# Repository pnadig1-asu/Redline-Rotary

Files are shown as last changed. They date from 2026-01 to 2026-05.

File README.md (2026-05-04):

<<<<<<< Updated upstream
This is the redline github repository

Phase 1 Video
https://youtu.be/27UCl4HXXh4

Phase 1 report can be found with the file name "MEE 342 Phase 1 Report.pdf" in the Github
=======

Phase 2 Video: https://www.youtube.com/watch?v=lnX_TSrsm9A

Phase 2 report can be found with the file name "MEE 342 Project Phase 2.pdf" in the Github
>>>>>>> Stashed changes

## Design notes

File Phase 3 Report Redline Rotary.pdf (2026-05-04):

Video: https://youtu.be/im36eBFv-yQ

### 1. Phase 3 report:

o Fabrication details (filament type, printer, settings, number of reprints) o Assembly procedure and challenges
o Test procedures, results, and interpretation
o Comparison with Phase 2 predictions (where applicable)
o Detailed discussion of failures, mistakes, and surprises
o Concrete list of design changes you would implement in a second iteration

### 2. Phase 3 video: Prototype Demo & Reflection

o Show the physical prototype operating.
o Demonstrate at least one test.
o Discuss major issues encountered and key lessons learned.

Phase 3 Report

Fabrication details
For this project, we used 2 bambu labs printers, mainly the bambu labs A1 mini and secondarily a P1S printer. The filament used was PLA plastic and with layer heights of .28 mm with supports enabled. The only part that needed to be reprinted was the rotors because the original print’s supports were not adequate enough, causing some overhang error. The print was also printed at 50% scale in order to preserve filament and print time.

Assembly procedure and challenges
For assembly, a lot of the parts had to be sanded down in order to fit accordingly, with the tolerances being pretty tight for a lot of the parts in order for the replica to work properly. Some challenges include the 3D printed gears being difficult working together and also not being able to use real lubrication for the plastic model. The surface roughness also caused some issues with the print and would cause poor sealing. The apex seals were not printed to stop the friction from being too overpowering to turn the rotors. Lastly, printing in PLA plastic means that the model would not be very heat resistant and not be able to support actual combustion.

Comparison with Phase 2
When comparing the phase two part of this project we can see that some predictions of tolerance issues were correct as there are some contact issues between the rotors and the housing. This is easily solved by sanding down the rotors slightly to make room for smooth rotation while still being true to our original model. Overall phase 3 was just printing our model from phase two, however in the printing process there were some techniques used to improve the models operation. For example printing parts in a certain orientation so the printing lines are in the direction of movement or rotation instead of against which would increase friction and make the model run rougher.

Details of failures, mistakes, and surprises
During the printing process the eccentric shaft was very hard to print compared to all of the other parts because of its complex geometry. It required many reprints and tree support additions to make it work, these tree supports increased the amount of rough surfaces that needed to be sanded down but wasn't too big of a deal. One mistake/failure would be a slight tolerance issue between the rotor and housing that made operation rougher and more difficult.

Test Procedure
Initial testing of the rotary engine was conducted by manually rotating the assembly to check for proper movement and clearance of all components. Observations focused on rotational resistance, consistency of motion and interference between specific parts. Following the initial evaluation, modifications were made to improve the prototype. The rotor and driveshaft were sanded to reduce roughness, and a lubricant was applied to decrease rotational resistance further. Additionally, the inner surface of the rotor housing was sanded as well to improve smoothness and better approximate the low friction conditions present in real rotary conditions. The model was then re-tested for rotational resistance under the same conditions

Results and Interpretation
During initial operation, the model exhibited significant rotational resistance and occasional binding due to the tight tolerances and relatively rough surface finishes of some of the higher tolerance parts, most notably the rotor, driveshaft, and rotor housing inner walls. After surface finishing and lubrication, the rotational motion improved significantly, requiring less effort to operate and resulting in more uniform motion of the rotor.

The observed improvements in rotational motion and elimination of binding is consistent with fundamental engine mechanics. In real rotary engines, journal bearings and continuous oil lubrication drastically reduce friction and wear between the rotor and shaft. Additionally, chromium plated housing inner walls provide highly efficient low friction surfaces for rotor motion. By smoothing the components using sandpaper and applying a graphite based lubricant, the model more closely replicates real rotary engine conditions and allows others to understand the mechanical properties of these engines. The results indicate that surface finish and lubrication are critical factors in achieving smooth and efficient rotary engine operation.

Design Changes in a Second Iteration:
Apex seals, ball bearings, better material(more heat resistant plastic)
For a second iteration, we would improve our prototype by moving beyond the current PLA used and focusing more on durability, sealing and smoother motion. Adding apex seals at the rotor tips to the prototype would greatly reduce the leakage between chambers. Integrating ball bearings to the design would help reduce friction, improve shaft alignment and make overall rotor movement smoother and consistent. We would make the second iteration out of a more heat resistant material such as a plastic or ABS. This would help better handle friction and temperature rise in operation of the prototype. These changes would make our design more mechanical, reliable and closer to a completely functional prototype of a wankel rotary engine.

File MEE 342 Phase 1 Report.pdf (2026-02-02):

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
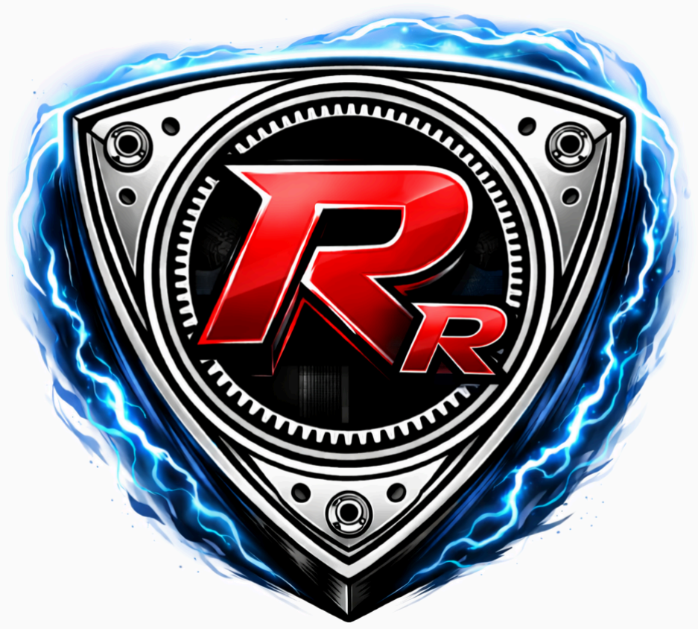
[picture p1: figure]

Phase 1

https://youtu.be/27UCl4HXXh4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 Executive Summary

The Wankel rotary engine converts the chemical energy of gasoline into mechanical torque using a rotating triangular rotor instead of reciprocating pistons. Unlike conventional internal combustion engines, it operates within an epitrochoid-shaped housing and produces power through continuous rotary motion, resulting in smoother operation, fewer moving parts, and a high power-to-weight ratio.
Each rotor creates three separate combustion chambers that simultaneously cycle through intake, compression, combustion, and exhaust phases. The rotor turns on an eccentric shaft with a fixed gear relationship, where the shaft rotates three times for every one rotor revolution. Proper operation depends on tightly sealed chambers, controlled air-fuel mixture, spark ignition, and effective lubrication and cooling systems. Many designs also inject oil into the intake flow to lubricate seals.
Key subsystems include the fuel delivery system, lubrication network, spark ignition system, and either air or liquid cooling. The most critical components for durability are the apex and side seals, their spring loading, and the thermal and lubrication controls that protect them.

Primary failure modes include apex seal wear or fracture, bearing damage from poor lubrication or overspeed, overheating and thermal distortion, and oil metering failures. Seal failure is especially critical because it leads to compression loss and major performance degradation.

The reference design described is a scaled version of a 1.3 L rotary engine with a 2:3 stationary-to-rotor gear ratio, defined rotor geometry, and tight sealing tolerances. Rotary engines are commonly used where compact size, smooth operation, and high power density are valuable, including UAV systems, automotive applications, and hybrid generator range extenders.

How the Wankel Rotary Engine works
Much like a conventional piston internal combustion engine, the purpose of the wankel rotary engine is to convert chemical energy from gasoline into mechanical energy. Also similarly, the engine does this by compressing and igniting air-fuel mixtures to harness the explosion’s energy as torque. Where the wankel rotary engine differs from traditional ICE’s is in its geometry; resulting in a unique set of advantages and disadvantages.
This engine is a reciprocating, four-stroke system that operates three combustion chambers per rotor assembly. That means that each unit of this engine intakes air-fuel mixture, compresses it, ignites it to harness energy, then forces out exhaust gases cyclically in three different instances concurrently. It accomplishes this using an epitrochoid-shaped housing with a curvilinear equilateral triangle shaped rotor inside that rotates on a 3:1 speed ratioed eccentric crankshaft. This system is then completed by sealing the combustion chamber, adding intake and exhaust ports, then typically a spark-plug ignition system and appropriate cooling and lubrication systems.

Key Components

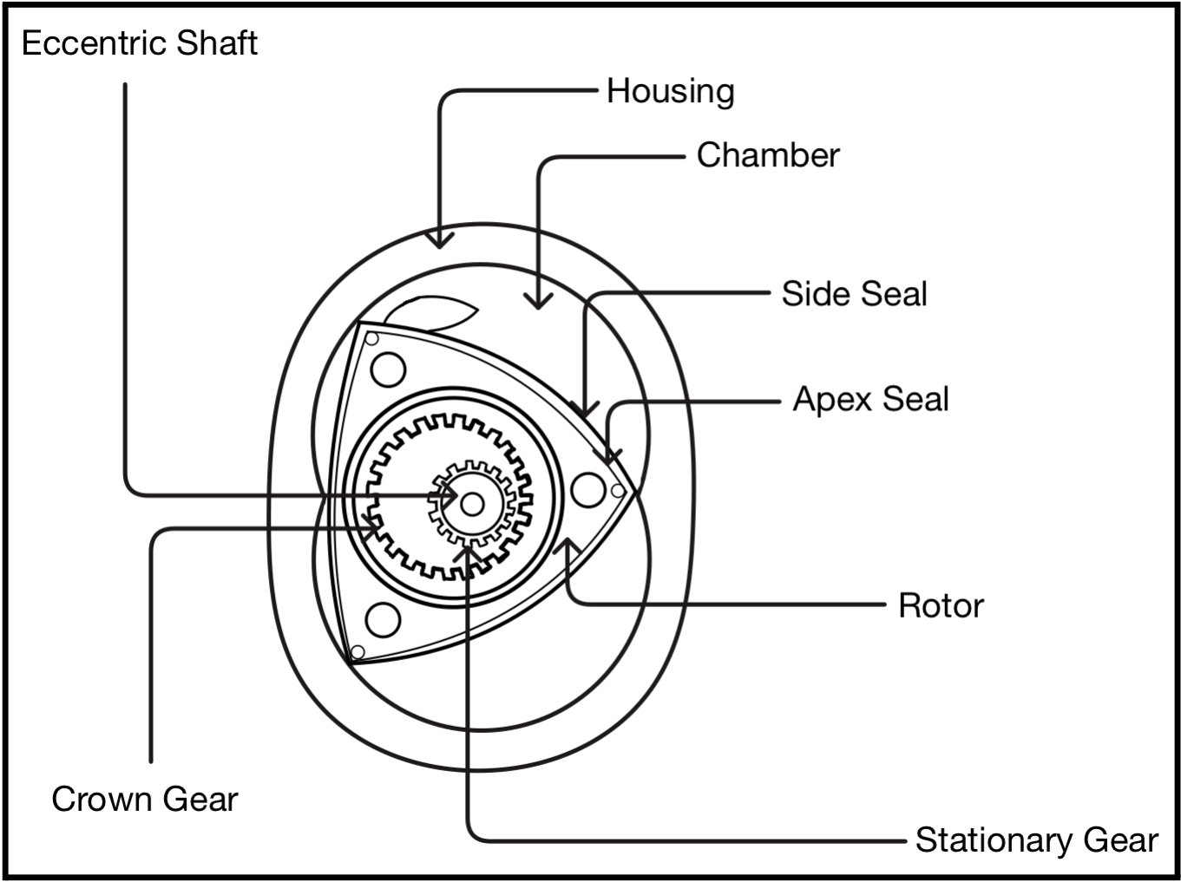
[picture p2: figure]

Housing (aluminum with chrome plating) Rotor (cast iron)
Eccentric shaft (machined steel) Stationary gear (hardened cast iron) Rotor bearing (aluminum)
Spark plug (iridium aluminum oxide) Apex seal (and springs) (graphite) Side seal (and springs) (steel) Coolant/Oil O-rings (viton)

Subsystems
Fuel system - This engine requires a precise air-fuel mixture to achieve proper combustion. Fuel is mixed with air through a carburetor or fuel-injection system. A crankshaft angle sensor, exhaust gas oxygen content (lambda) sensor, and air pressure sensor may be used to optimize fuel quantity and mixture timing. Many wankel systems mix lubrication into air-fuel mixture much like a two-stroke engine.
Lubrication system - The rotor bearing is the main point of lubrication in a wankel rotary engine. The bearing is oiled by passages through the middle of the crankshaft that contain pressurized oil from the oil pump. Oil then circulates around the rotor bearing and through the inside of the rotor. Oil can also be mixed into the air-fuel mixture to lubricate external rotor seals like the apex and side seals.
Spark system - Very few compression ignition wankel rotary engines exist, meaning spark ignition is common practice due to consistency and engine knock prevention. Either crank angle sensor or magneto spark systems are implemented to ignite non-CI fuels.
Cooling system - Depending on application, water cooling may be needed to keep engine temperatures within operating range. Smaller UAV applications utilize fins for air cooling, while automotive applications use coolant passages, a water pump, and a radiator. An oil cooler is sometimes utilized to include cooling from the lubrication core of the system.

Failure Modes
Seal destruction:
- Detonation (usually due to overheating)
- Lubrication problems
Bearing destruction:
- Lubrication problems
- Revving too high
Overheating/thermal distortion:
- Poor cooling design
- Uneven heat rejection
Oil Metering Failure:
- Pump/injector malfunction

The main failure mode is the apex seals, which provides sealing between each chamber on the tips of each triangular rotor. This can be caused by wear, improper lubrication between the components, or excess heat, which eventually leads to compression loss and power drop. Another cause of apex seal failure is detonation, which is when the air-fuel mixture combusts prematurely; the pressure from the detonation can shatter the apex seal while it is not in position to take that kind of force. This failure is catastrophic to engine operation, with reassembly only possible if loose seal pieces do not gash housing and rotor components.

The most important components to minimize failure are the material used for the apex seals, the apex seal springs, and the fuel, lubrication, and cooling systems. The apex seal material used changes the wear resistance and longevity of the seals. The seal springs are important because they make sure that the seals maintain consistent contact with the rotor, optimizing compression. All of the fuel, lubrication, and cooling systems are important components because if they are not operating properly, it could cause premature wear/overheating to the engine which would cause it to fail.

Critical design Parameters
Our design will be a scaled-down version of Mazda’s 13b wankel rotary engine.

The gear ratio of stationary gear to rotor gear is 2:3 with a teeth count of 36:54 some other critical dimensions being a radius of 105 mm from rotor center to apex seal point, chamber/rotor width of 80 mm.
Eccentric shaft diameter (rotor bearing diameter -> clearance)
Engine displacement 1.3L
15mm crank offset (stroke)
Sealing apex and side seals (too large of seals -> interference damage, too small -> no compression)
Epitrochoidal housing and curvilinear equilateral triangle rotors with widths of 80mm Crankshaft spins 3x as fast as the rotor, so one rotations of the rotor is 3 rotations of the crank

Applications
UAV - Single rotor, air cooled, small, high power to weight ratio, low vibration, fuel versatility Automotive - 2 or 3 rotor, coolant and oil cooled, larger displacements
Hybrid Power Generation - engine can act as a generator for electric motors with high fuel efficiency, can be used as a range extender

Kinematics
The kinematic relationship between the rotor and the stationary gear can be described as

ω

r = ω
c

(1 −

Ns
Nr

)

Where:
ω is the angular velocity of the rotor
r
ω is the angular velocity of the eccentric shaft
c
N is the number of teeth on the stationary gear
s
N is the number of teeth on the rotor gear
r

In most wankle applications,

Ns
Nr

=

2
3

Sources
https://patents.google.com/patent/US5305721A/en

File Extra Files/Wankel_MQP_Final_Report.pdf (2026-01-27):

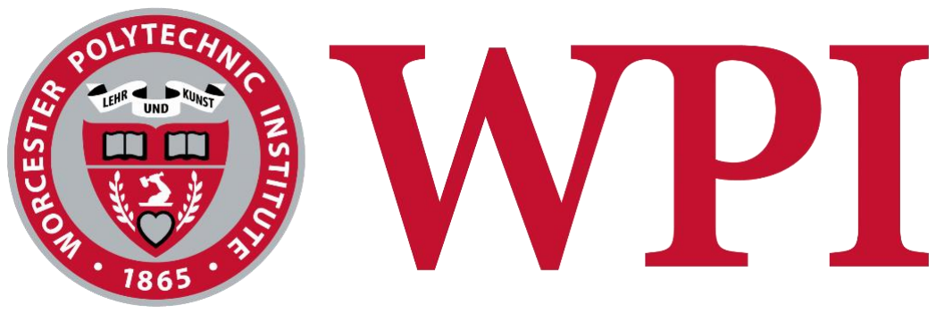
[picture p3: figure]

### Designing and Manufacturing a Rotary Wankel Engine

A Major Qualifying Project Submitted to the Faculty of WORCESTER POLYTECHNIC INSTITUTE
in partial fulfillment of the requirements for the Degree of Bachelor of Science in Mechanical Engineering

By:

William Hopkins
Patrick Leach
Yutai Han
Ryan Gillett

Advised By:

Selçuk I. Güçeri

24th of March 2023

This report represents the work of one or more WPI undergraduate students submitted to the faculty as evidence of completion of a degree requirement. WPI routinely publishes these reports on its website without editorial or peer review. For more information about the projects program at WPI, see http://www.wpi.edu/Academics/Projects. (https://www.wpi.edu/project-based-learning)

Abstract

Through thorough design and manufacturing, our team was able to model and construct a rotary engine. We did this by 1) researching different Wankel engines 2) computing the math for the engine shape 3) designing our model 4) machining the parts and 5) constructing the engine and testing it. Once these steps were completed, we had a functioning model of a Rotary Wankel Engine.

The Wankel engine is a type of rotary combustion engine that converts thermal energy into mechanical energy through eccentric rotation movement. Compared to the traditional Otto cycle combustion engine with reciprocal pistons, Wankel engines have fewer moving parts, and therefore are proven to be more compart and smooth during operation. As the world is moving into a unified effort of decarbonization and downsize of combustion engines, Wankel engines are slowly being brought back as a compact solution for source of energy. To have a better understanding of the operation of Wankel engines, and to produce a functioning prototype, the team conducted extensive literature examination and review of the early documents of the development of rotary engine.

Through extensive computation, the team was able to create the epitrochoid shape of the housing that the rotor is sitting in and create the rotor that has similar shape to a Rouleaux’s triangle with correlating dimensions. The material of the parts was selected accordingly from the team’s research on past development and within the parameter of the project budget allowance. The dimensions were then transferred to computer-aided design and manufacturing software to start the manufacturing process.

Executive Summary
Goals and Objectives

The goal of our team’s Major Qualifying Project was to design and manufacture a rotary Wankel engine; recreating the famous engine with modifications of our own to improve the system. In this MQP we worked with the manufacturing laboratory of Washburn at Worcester Polytechnic Institute to machine and construct our rotary Wankel engine.

Proposed Solutions

To carry out the manufacturing, we followed the designing and iterating process shown in many WPI classrooms. We defined our problem by reading articles and interviewing professor Güçeri on the downsides of the rotary engine. We mapped the process and determined the key metrics of the engine to focus on would be:
- Apex seal spring retention
- Electronically controlled ignition timing
- Material choice to avoid pitting and wear
Results

From our research, design, and manufacturing we created a Wankel engine with SolidWorks, Esprit, and the machining tools located in Washburn labs. SolidWorks allowed us to design each part to the specifications of Mazda and other Wankel examples and place it into an assembly for easy view of construction. The software Esprit was the transition from SolidWorks into CAM “g-code” which then allowed us to take our raw material and machine into the parts we needed.

Our newly constructed engine may not solve the downsides of previous Wankel engines, however with the rise of rotary engines once again, we were able to develop a deeper understanding of how the engine itself works. Our mission with this project includes a deeper understanding of a Wankel engine as well as insight and practice with advanced design techniques and manufacturing technologies through the manufacturing of an engine. Knowledge gained will be used demonstrate and explain to others how the engine itself functions.

Acknowledgements

### We would like to thank several individuals for their

contributions and support of this project.

Selçuk I. Güçeri, WPI Mechanical Engineering Professor, and our project sponsor, for supporting us throughout our MQP, guiding us on where we needed to go next, and his continuous support and enthusiasm for our project.

The Mazda Engineering Team for their base design of the Wankel Rotary engine, and their parameters for which we based ours of off. Without their data we would not have been able to accurately design the rotor or rotor housing without measuring a physical model. Their equations also allowed for the scalability of the parts.

The Mechanical Engineering Department for the use of Washburn Laboratories and for them ordering tooling and material for us to create our engine.

The L. S. Starrett Company for assistance with tooling and allowing us to cut our large stock pieces to size.

# Table of Contents

# Table of Figures

Introduction

Automobiles and similar modes of transportation are necessary for modern day lifestyles. These automobiles require engines, engines which already exist but may have glaring flaws. The goal of our team’s Major Qualifying Project was to design and manufacture a rotary Wankel engine; recreating the famous engine with modifications of our own to improve the system.

The combustion engine was the driving force behind the industrial revolution and the main powerhouse of human innovation for past decades. Many types of combustion engine were invented throughout the history intended to be used for different purposes. The most famous being the reciprocating piston engine that are commonly used in most of the motorized transportation. Other combustion engines include turbine engines mostly used in the aviation field, and the rotary engine; an alternative solution to the piston engine that has been utilized in different application.

The rotary engine’s initial application was in motorcycles, due to its relatively small size and high-power output. Rotary engine reached its peak popularity at the end of the 20th century, where Mazda motor corporation introduced it in a variety of the mass-produced road cars, as well as some high-performance race cars. However, the production of the rotary engine was slowly phased out at the turn the of century due to its relatively high consumption of fuel, and the inability to burn fuel cleanly. These were some of the deciding factors at the time; the scarcity of oil, and a general direction for automotive manufacturers to produce more efficient and clean burning cars. Even though the mass production of rotary engine equipped cars ended more than a decade ago, the search for a new application of rotary engine never stopped. Its unique design and compactness keep the search ever moving. There have been series of attempts to revive the rotary engine with modifications to the original design, or as a secondary source of power.. This project will focus on having a rotary engine which is smaller in size than the regular Mazda motor, performing on a similar power to weight ratio.

Background

The rotary Wankel engine was first designed by German engineer Felix Wankel in 1929. The engine was designed to create rotational motion by converting pressure, providing more unform torque, less vibrational movement, and to have a lighter weight than the average piston engine (Hege, 2015). NSU Motorenwerke AG acquired the patent, then licensed the design to other companies around the world.

The rotary engine has a four stroke cycle similar to a piston engine. However, the combustion cycles occur at different locations within the combustion chamber in the rotor housing. The intake, compression, and exhaust of the air is all controlled by the rotation of the rotor, while the spark plug located on the housing ignites the compressed air to initiate the ignition stage. Due to the decreased number of the moving parts in the combustion chamber, rotary engines are able to achieve a higher revolution per minute than traditional piston motors. A visual representation of a combustion cycle is shown below.

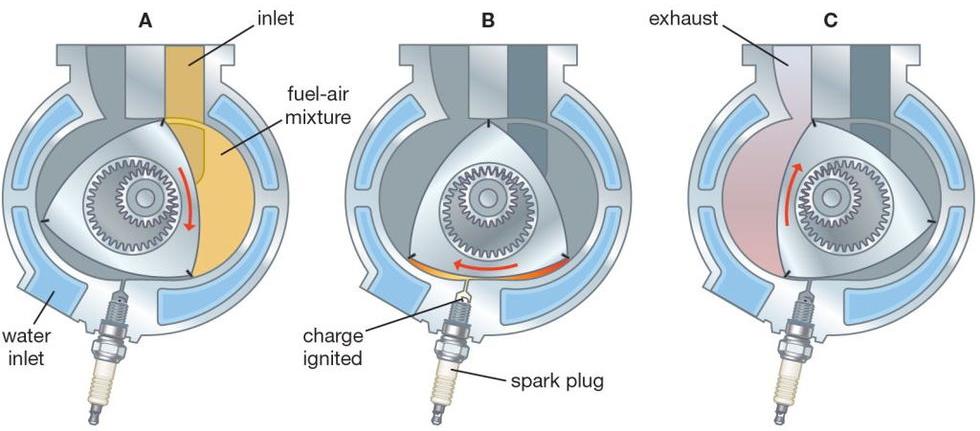
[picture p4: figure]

Figure 1: How a Wankel rotary engine works (Jancer, 2018)

Many of the major automotive companies such as Alfa Romeo, American Motors, Citroën, Ford, General Motors, Mazda, Mercedes-Benz, Nissan, Porsche, Rolls-Royce, Suzuki, and Toyota, purchased the license, attracted to its smoothness and light weightiness. Rotaries were utilized in airplanes, motorcycles, but mostly automobiles. Only a few of these companies ultimately followed through with the license however, Mazda, Citroën, and NSU continued to work on the engine. Mazda was the most influential and successful in their research and development on the Wankel engine. Over the years, Mazda has produced many famous cars with the Wankel such as the RX-7 FB, FC, and FD, the RX-8, the 787-B four rotor, and the Cosmo.

The Mazda RX-7 is one of the main sources of inspiration for this project. It is a wonderful automobile, one that has faded out of mainstream due to the issues which arise from the rotary Wankel engine. To revive the Wankel engine would be a magnificent feat, hence why our team has decided to redesign, improve, and construct the engine.

To design and build a rotary engine, there are many more requirements than one may expect. Researching the epitrochoid equations for the rotor housing and rotor requires intense analysis of Mazda technical books, online forums, and insight from Professor Güçeri. Then one must design and create the eccentric shaft, an offset shaft to convert the rotor motion into the drive train. This will require more research and a difficult manufacturing process. Once all the major components of the engine have been created, the seals, fasteners, and extra elements must be either purchased or handmade to construct a functional engine.

Methodology Timeline and Overview

A Term:
During the first of three terms in our group's development time, we began ideating, researching, and designing the engine, while also writing our final report. The three main components which were designed in CAD were the rotor, the rotor housing, and the eccentric shaft. All equations and shapes are modeled after Mazda’s patent for the rotary Wankel engine, specifically the 13B.

This process started with the equations for the rotor housing. First modeled in Desmos then SolidWorks, the equation below is foundation for the entire housing.

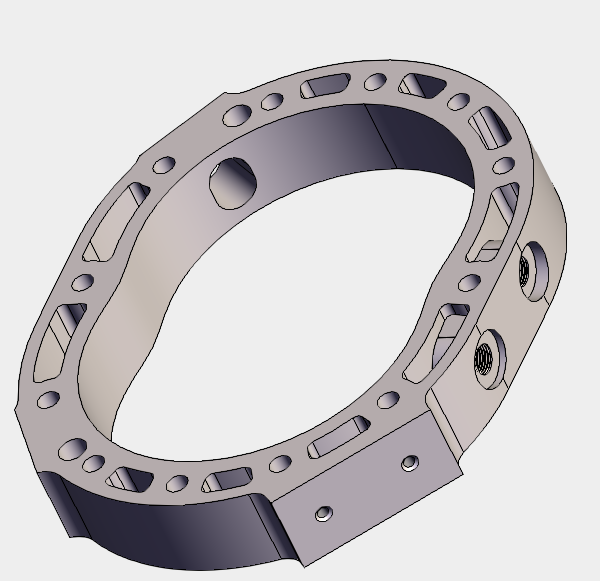
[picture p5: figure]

Figure 2: Rotor Housing

The rotor housing also needs many holes and supports to properly function in its design. Water cooling holes are strategically placed to allow more even cooling of the system. One of the downsides of the rotary engine compared to a piston engine is the uneven heating of the system. Exhaust and combustion take place in certain spots of the rotary, with one segment being just compression and intake, significantly cooler operations. Along with the cooling channels, intake, exhaust, spark plugs, and mounts all needed to be considered and included as well.

The next part of the assembly which was modeled was the rotor which goes within the rotor housing. The rotor is one of, if not the most, essential components of a rotary Wankel engine. To form the outline of the shape, Mazda does provide equations, however these equations are almost impossible to implement into SolidWorks. The equations are all cyclical, continuously calculating the distance from the rotor housing as it goes around in its epitrochoid shape.

The rotor has more components which improve its ability to function. First, there needs to be chambers on the edges for compression. These were determined by measuring the ones on Mazda’s rotor, and then scaling it down. In the center of the rotor there is gear teething which connects the rotor to the eccentric shaft. In the final stages of construction, there will be seals along the edge of the gear hole.

The third component which our team began to design and develop was the eccentric shaft. This is one of the more necessary parts for the engine to run. The eccentric shaft is what takes the rotational motion of the rotor and transfers it to the drivetrain. In the simplest terms, it is the connector from the engine to the transmission to then turn the wheels. In theory, the eccentric shaft is a simple piece, a cylinder with some eccentricity set at 3.5/6.2 or 0.5645in. There are not many extra holes, or components coming from it. The issue with the eccentric shaft will be the machining of it. In a lathe the shaft will have to be taken out, and perfectly set to have the eccentricity of 3.5/6.2. The displacement of our engine was calculated to be 488.82cc, this was later confirmed by measurement in Solidworks that gave a displacement of 559.82cc. The difference in volumes was due to the cavities around the apex seals.

B Term:

In the second of our team’s three terms to complete the project we finalized the design of the engine and began the manufacturing process. The first hurdle of the team was correcting the gearing within the rotor and the eccentric shaft. The original design had a gear ratio of 1:3, but the correct gearing ratio is 3:2. This was a simple fix to correct, requiring only to change the sketch of the rotor, and changing the original number of teeth from 36 to 54, and the end of the eccentric shaft from 12 to 36. Doing this also increased the size of the gear hole, allowing for a safer and more reliable gear system.

Our team began researching materials to utilize in the manufacturing of the engine. This proved to be slightly difficult. With the status of supply chains and material prices, the pieces we wanted to use were significantly more expensive than we imagined. By doing some slight redesigning and rethinking of materials we were able to drop some of the costs. These costs were supported however by both the MQP grant given to teams, and the support from our professor and contributions from individual team members. For the housing we decided to use 4140 steel, the rotor was decided to be machined from 6061-T6 aluminum, and the other parts were either ordered or made from 4140 steel.

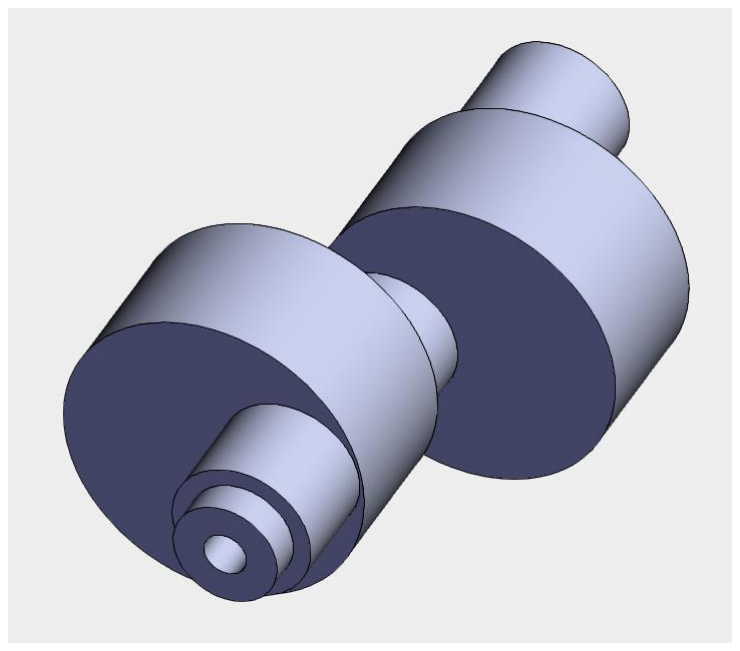
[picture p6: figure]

Figure 3: Eccentric Shaft Model

C Term:

Now equipped with the materials we needed to machine our parts; we began our manufacturing in early January. All the SolidWorks parts were transferred over to Esprit, the CAM software used to calculate tooling paths for the machining. With the help from Washburn labs at Worcester Polytechnic Institute, we were able to machine out the engine pieces. The process took a while, and many nights were spent watching the mills and lathes to ensure a smooth and successful operation.

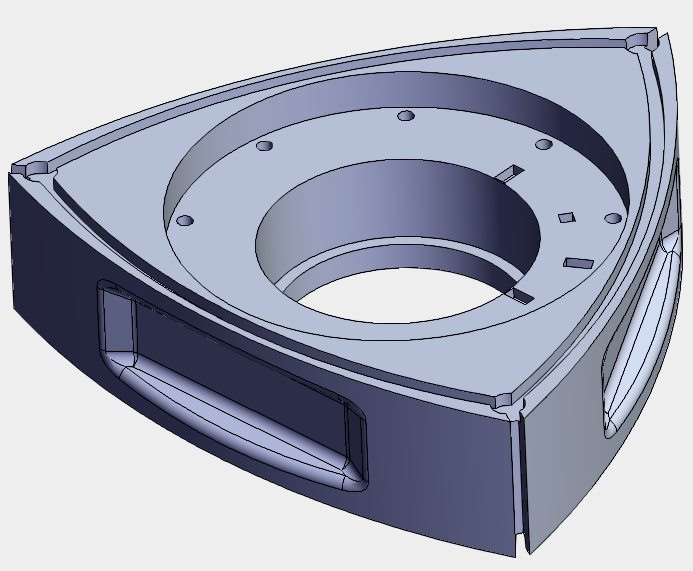
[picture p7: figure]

Figure 4: Rotor Model sans Seals & Gear

Over the weeks from January 11th to March 3rd, the rotary engine parts were machined, cleaned, treated, and assembled into our groups’ rotary engine. By using 4140 steel, our materials were harder than the normal materials machined in the labs. Our group had to custom order ¼” and ½” ferrous tooling, which resulted in a significant holdup. Additionally, the initial round of tooling was economy tools which, during the milling of one of our irons, broke due to poor quality. Despite these setbacks, we were able to continue forward and have most of the parts machined out for the engine by the end of the term. We constructed and prepped the engine in the final week, with all systems hopefully fully prepared for project presentation day.

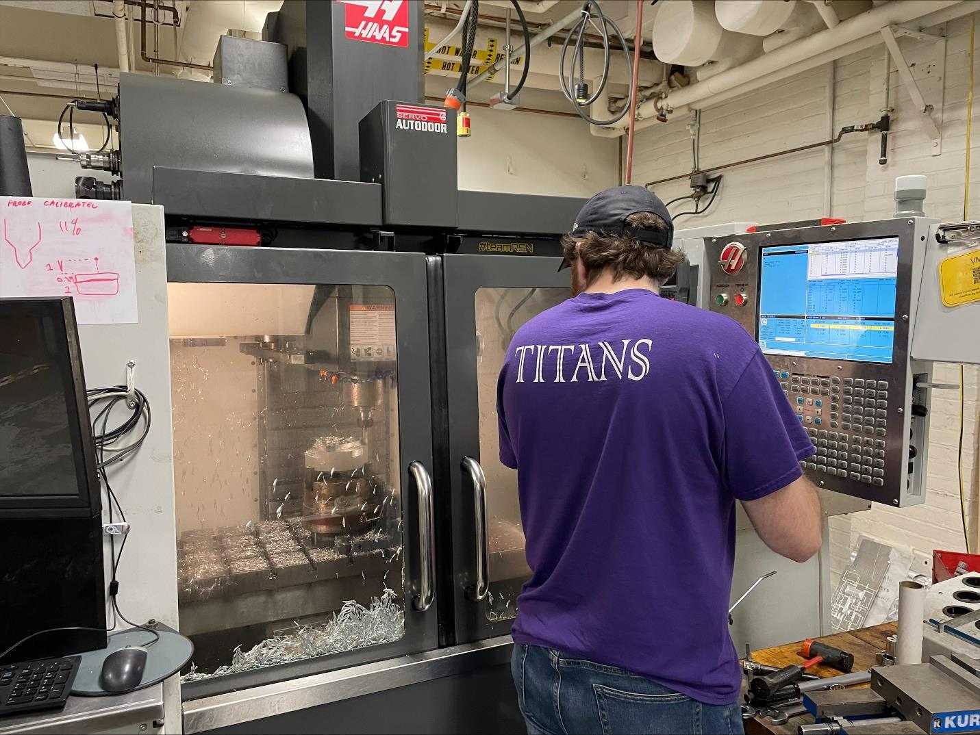
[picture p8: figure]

Figure 5: Patrick Machining with HAAS VM2 in Washburn Labs

Engine Components and our Research

Irons

The irons are parts of the engine that sit on the sides of the rotor housings. They are responsible for sealing the combustion chamber on the side profile of the rotor. Because the irons are the surfaces that the rotor will be having constant contact at high revolutions with, they are to be surfaced on the face to ensure flatness and smoothness. Also, due the fact that the irons cover a large surface area of the combustion chamber, they have water jackets running through them on the peripheral edge to ensure proper cooling. During our initial design, the exhaust port was located on the iron themselves. This caused exhaust gas to be able to escape through holes on the iron during part of the combustion cycle. However, it was later discovered that the design with the exhaust port on the iron would add significant weight, thickness, cost, and general complexity of manufacturing to the design. The exhaust port was then decided to be relocated to the side of the rotor housing – a design change that proven to be quite beneficial during our manufacturing phase.

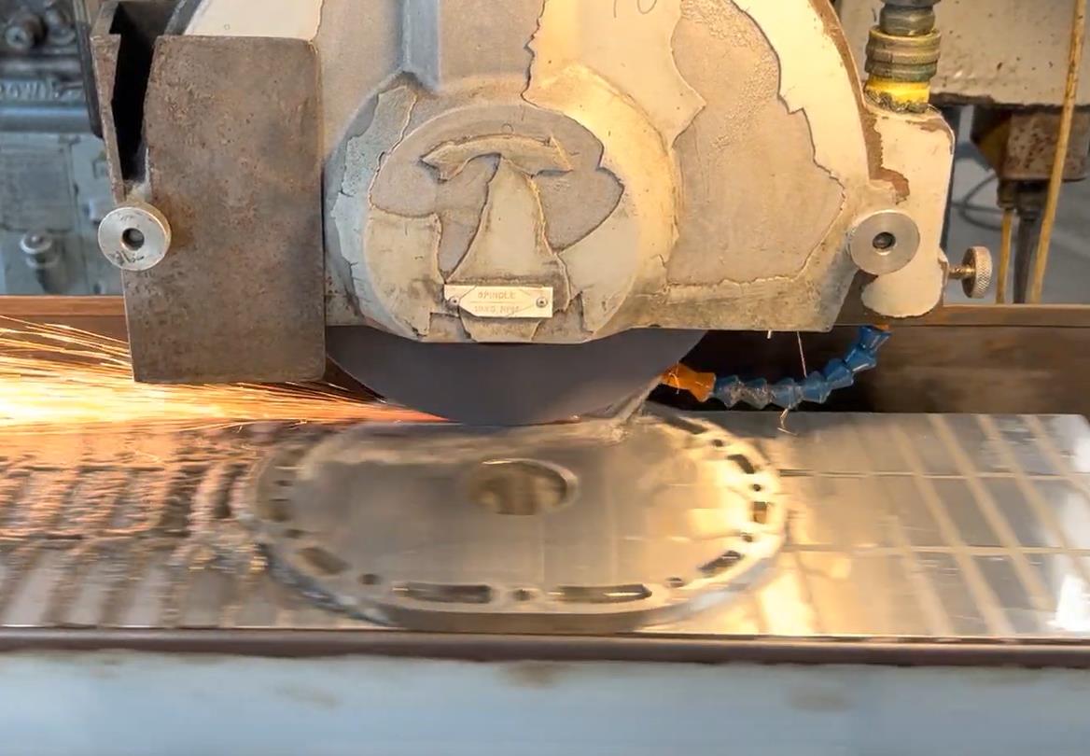
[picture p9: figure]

Figure 6: Ce Iron During Grinding

To ensure the flatness and smoothness of the irons, all surfaces contacting the rotor were finished with a surface grinder. This greatly improved the surface conditions on the iron faces and serves to improve the overall tribological interaction between the face seals and the irons.

Housings

The housings are another important aspect of the Wankel rotary engine. The inside walls must be made of a strong material to withstand wear from the apex seals, and also have high temperature resistance, as the combustion is happening within this chamber. The most important design feature of the housing is the epitrochoid shape, given by the equations below:

Both equations are bounded between 0 and 6*pi

X=(.5645)*cos(t)+(3.5)*cos(t/(3))+(.0175)*cos(t/(3)+acos((3*(.5645)*cos((2/3)*t)+(3.5))/(9*(.5 645)^2+(3.5)^2+6*(.5645)*(3.5)*cos((2/3)*t))^.5))

Y=(.5645)*sin(t)+(3.5)*sin(t/(3))+(.0175)*sin(t/(3)+asin((3*(.5645)*cos((2/3)*t)+(3.5))/(9*(.56 45)^2+(3.5)^2+6*(.5645)*(3.5)*cos((2/3)*t))^.5))

These equations give the shape which the corners of the rotor follow and allow for the eccentricity ratio of 3:2 to remain constant. This shape also allows for the intake, compression, combustion, and exhaust to happen along with the rotor.

These housings also contain holes along the walls, allowing for water cooling, and the assembly of the engine. There are a few access ports along the outer faces, providing access for spark plugs and an exhaust port.

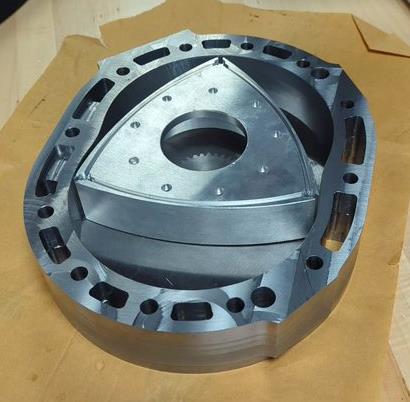
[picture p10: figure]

Figure 7: Housing with rotor inserted

Rotors

The rotor is one of the most important aspects of the Wankel rotary engine. It is the component which produces the rotational movement required to generate torque to move the wheels. The rotor is responsible for intake, compression, ignition, and exhaust. Through a connection to the eccentric shaft by a phasing gear, the rotor, or multiple rotors, translate the power into a usable form. Compared to the more common piston engine, rotary engines do not have reciprocating parts, allowing for a much higher RPM, and power to weight ratio. When designing a rotor for a rotary engine, one must keep in mind the material choice, and pocket designs on the side. These pockets allow for more compression, and therefore more power. Mazda has a set design for these compression pockets, however, there has been research (Boughou, Smail, Mohiuddin, 2020) on which orientation is the most efficient. With our rotor, our team decided to replicate to the best of our ability, the design that Mazda uses for their rotors.

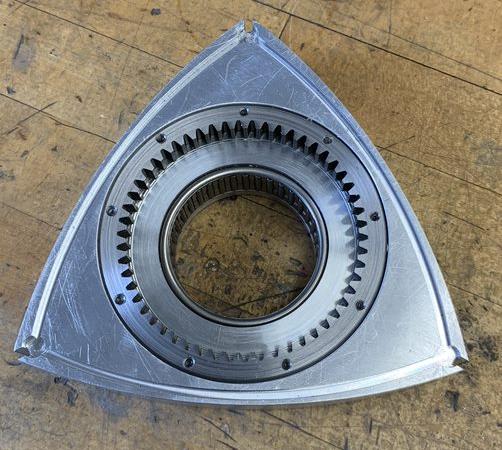
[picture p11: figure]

Figure 8: Our machined rotor with phasing gear

Seals

Sealing within the Wankel engine is crucial to engine operation. In particular, the seals on the face and points of the rotor are what allow for compression to be built. The seals at the points are called “apex” seals while the seals between the rotor and the irons are “face” seals. Apex seals remain in contact with the housings while the face seals contact the irons. On the corners of the rotors are the “corner” seals. Corner seals are responsible for bridging the gap between the face seals and the apex seals (Rotary Seal Design Guide, 2018). Within the apex and face seals are small springs which provide a light force to keep the seals in contact with their respective surfaces.

In previous Mazda production engines, apex seals were the most common point of failure. The most often failure would be excessive wear of apex seals causing a loss in compression. Additionally, wearing of face seals can cause excessive oil consumption and further loss of power. As a result, Mazda placed a great deal of effort in the design and selection of materials for the seals. They used a (Moskowitz, Uy, 1976) cemented carbide using a molybdenum and nickel binder. The composite material allows for wear resistance while providing sufficient lubrication to prevent housing damage.

For our project, the process to fabricate custom seals following Mazda’s method would exceed our time and monetary constraints. As a result, bronze was used as an alternative. Bronze has excellent wear characteristics which should preserve the life of the housings while still sealing the combustion chamber. Additionally, bronze is moderately hard (Rockwell B90) which should prevent premature failure due to wear. Bronze 510 rod is used to form the corner seals while 1/8” thick bronze 510 plate is cut into strips to form the apex seals. A small 1095 strip of spring steel sits in a machined groove in the apex seal to keep constant contact with the housing. Adapting the design allowed for the seals to be completely machined in the Washburn Labs machine shop.

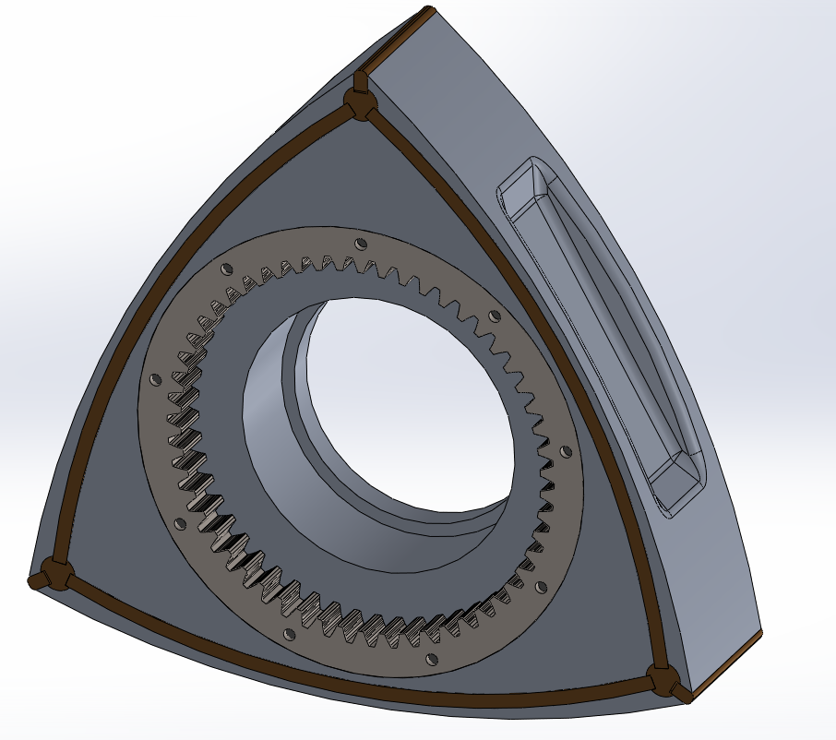
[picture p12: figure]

Figure 9: Image from SolidWorks of rotor with all seals. Seals are darker in color to indicate being made of bronze vs the aluminum rotor. Spring is hidden by the apex seal.

Phasing Gears

Another critical component in the Wankel engine is the phasing gears. The phasing gears are responsible for maintaining the angular position of the rotor with respect to the rotation of the eccentric shaft (Kulina, 1986). As a result, the apex seals of the rotor will remain in contact with the housing wall throughout the entire 360° rotation of the E-shaft. The phasing gears achieve the angular control by meshing the rotor to a gear fixed to the iron. The ratio between the rotor gear and the fixed gear is 2:3. The specific size of the gears is driven by the eccentricity in the E-shaft – a value determined at the start of the engine design. The eccentricity value is equivalent to the gear center to center distance. For material, the gears must be durable to wear but do not experience significant forces in operation – they merely maintain proper phasing of the rotor (Kulina, 1986); They should be made of a hardened material such as tool steel.

For our engine, the eccentricity value for the E-shaft is .5645”. With this value, a tooth count of 36 and 54 for the fixed and rotor gear respectively was chosen. The gear profile was generated using an online Gear Generator (https://geargenerator.com/) to reduce the total design time spent on the individual components. The generated profile was then imported to SolidWorks where it was used to construct the gears for the engine. Material for the gears was selected to be 4140 Alloy steel for its high wear resistance ease of machining on a wire EDM.

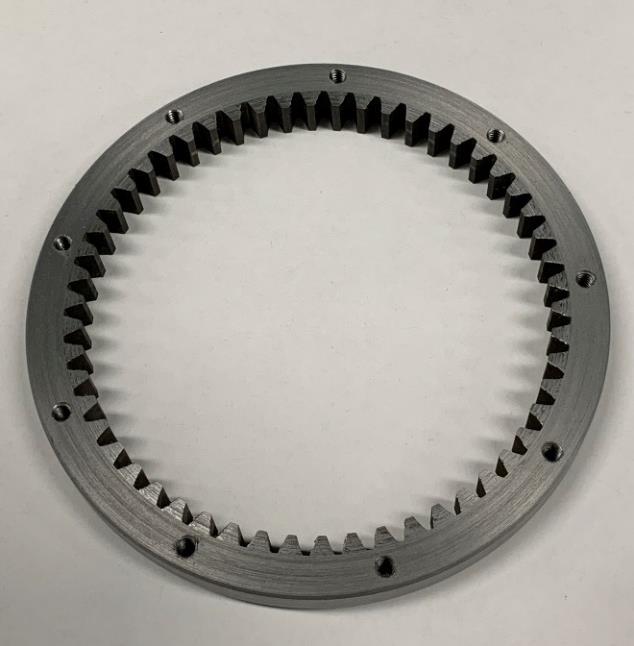
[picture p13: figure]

Figure 10: 54T Rotor Phasing Gear. Gear is machined to sit recessed in the rotor like seen in figure 8.

Eccentric Shaft

The eccentric shaft is the component which transfers the orbital motion of the rotor into pure rotation about the shaft’s main axis. The shaft is therefore responsible for transmitting the force generated by combustion and must have sufficient strength to resist torsional deflection. Since our engine had no requirements for torque or power figures and our budget was limited, it was decided to manufacture the eccentric shaft to make use of commonly available needle-roller bearings. This type of bearing was selected for its ability to handle high RPMs.

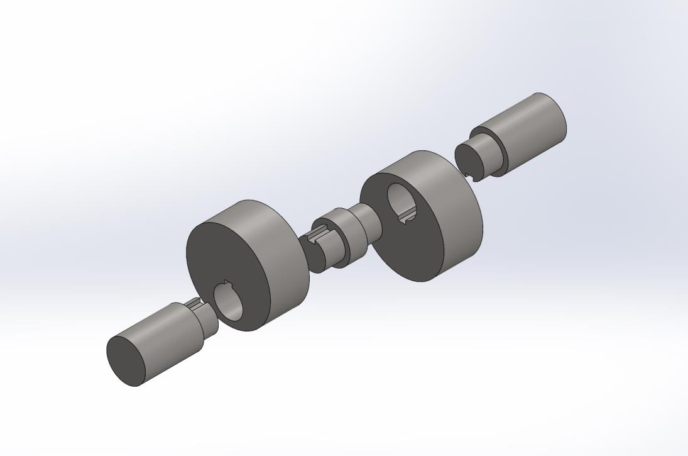
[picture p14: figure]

Figure 11: Exploded View of Eccentric Shaft

During the design of our eccentric shaft, a series of geometric limitations became immediately apparent. The outer diameter of the eccentric lobes which the rotor revolves around must be large enough to fully encompass the concentric shaft diameter. This is imperative for the assembly of the engine and is clearly seen on all other eccentric shafts. This was not obvious to the team during the initial design stages. The chosen solution was to use 55mm diameter lobes and 1” diameter on other portions of the shaft, doing such allowed us to minimize the distance between the lobe and main shaft while still using inexpensive, commercially available bearings.

To make manufacturing easier, we chose to make the eccentric shaft from multiple pieces. As seen in Figure 11, the final design of our eccentric shaft made use of reduced diameters keyed to the lobes of the eccentric shaft. The stepped diameter was machined to the same diameter as the bore to allow an interference fit of the two. While a multi-piece eccentric shaft may seem like an unorthodox design choice, Mazda themselves made extensive use of multi-piece eccentric shafts in their three-rotor street and four-rotor race engines; the latter propelling the only rotary-engine car to ever win the 24 Hours of Le Mans (Mazda), a testament to the strength of its design.

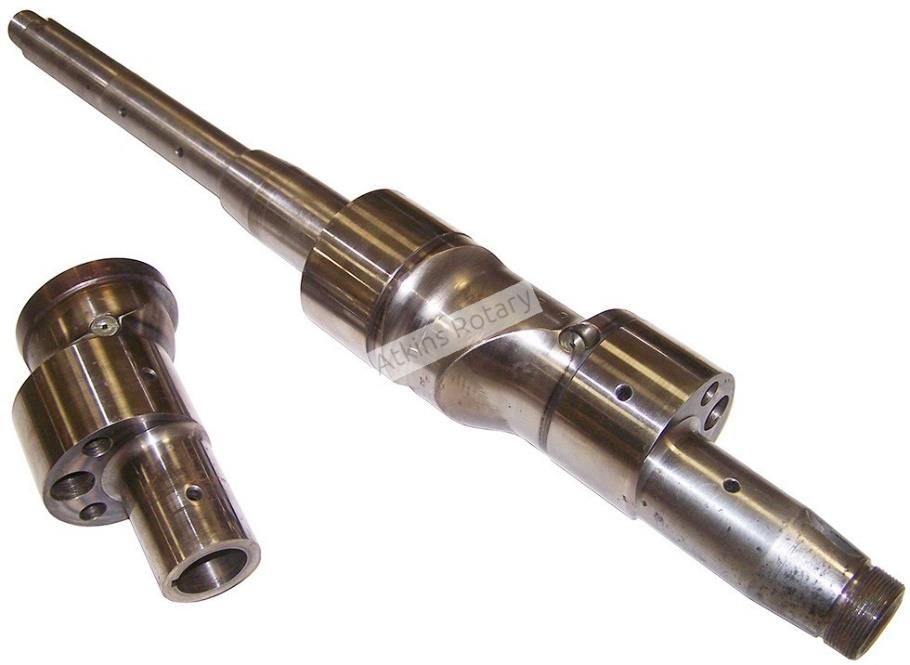
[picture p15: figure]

Figure 12: Multipart Eccentric Shaft (https://www.atkinsrotary.com/store/watermark/product/D/NF01-11-D00C-UsedDetail.jpg)

Manufacturing Considerations

Fixturing

During the manufacture of the engine, much was learned on the topic of workholding. The necessity to locate all parts consistently was made apparent by the fact that any misalignment between components in the assembled engine stack would cause either accelerated wear or a failure to function altogether. To overcome the challenge of misalignment in the X-Y plane on the HAAS VM-2 Milling machine, a locating plate was designed and machined. This plate provided two undersized reamed holes which were press fit with 0.375” precision ground dowel pins. The faces of the plate were left as factory-finished since the material used was Alcoa MIC-6, a cast 7000 series aluminum produced mainly for the purposes of fixturing. Inspection with a Starrett 711 dial test indicator in the machine showed no noticeable deviation in the materials thickness.

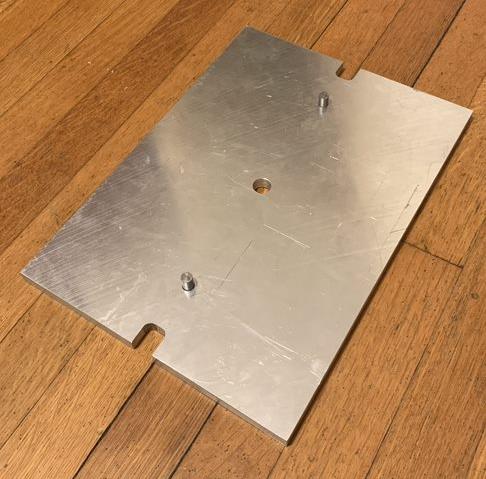
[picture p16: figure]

Figure 13: Fixture Plate for Housings and Irons

Not only did the fixturing of components require a special tool, but modifications had to be made to the components themselves to allow for their repeatable location. This was accomplished by adding a reaming operation to all holes on the engine’s perimeter. This allowed for internal, concentric location of the part – an ideal case when designing fixturing devices of any form (Carr-Lane). (https://www.carrlane.com/engineering-resources/fixture-design-principles/locating-clamping-principles) The resulting fixture system restricts the part’s degrees of relative to the machine to only Z-axis linear translation, this is then secured with conventional strap clamps to result in a firmly held and precisely positioned part.

Similar to how the housings and irons needed repeatable positioning, the rotors for the engine suffered the same issues. After initial shaping, the rotor needed the combustion pockets, apex seal and face seal grooves all milled. To make the setup faster and produce more repeatable accurate results, a fixture plate for the rotor was produced. The fixture plate was made from the same MIC-6 aluminum as the housing fixture plate but instead of pins for alignment, a shadow of the rotor outer profile was milled (see figure 12). When placed in the cutout, only a single bolt was needed to secure the rotor to the plate. The plate was milled with two positions for the rotor – one for the apex seal operation and one for the pocket operation. The shadow cutout would position the rotor so that the objective cutting area was easily accessible by the machine.

For machine setup and CAM generation, the origin of each operation was based on the fixturing plate. This made finding work offsets easier and more reliable throughout various setups. For cutting operations on the outside faces of the rotor, an angle fixture was used to orient the plate vertically in the machine. The use of a fixture plate in manufacturing the rotor allowed for consistent and accurate machined results.

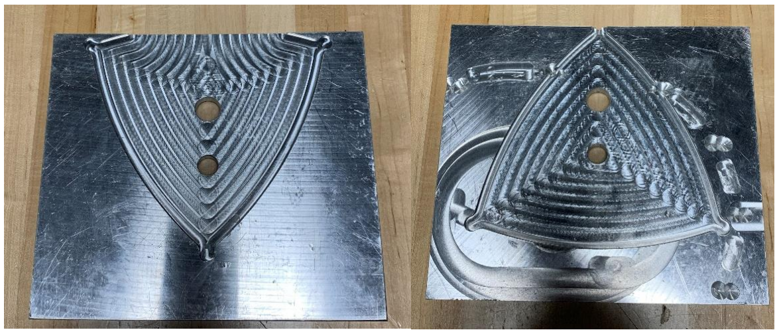
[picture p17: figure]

Figure 14: Fixture for rotors. Left cutout is used for milling rotor pockets. Right was used to mill apex seals. The right profile was also used to cut face seals. Both cutouts are located on opposite sides of the same plate.

Conclusion and Recommendations

Constructing something like this requires a lot of attention, detail, dedication, and knowledge of the tools to create it. This is most likely why car manufacturers are so highly regarded, as this technology can be extremely difficult to recreate with limited tools such as the ones provided by WPI. It can however be done. There is necessary research and planning when designing and orchestrating a project such as one of this caliber. It goes all the way from understanding SolidWorks design and designing for manufacturability, to running the CNC machines and understanding how the large manufacturing machines in Washburn work. Some of the more difficult aspects were the after-thought parts of the engine itself. Sealing, lubrication, ignition, timing, all the electronic and fluid parts of an engine many do not first consider when thinking about rotary engines.

If another team were to do this type of project again in the future, it is highly recommended to do plenty of planning and research and begin machining as soon as possible. This advice could go for any project, but without extremely skilled machinists such as Patrick and Will, another team may encounter problems along the way. By giving themselves more time, it allows for more time to adjust from any mistake.

Building an engine not only is a mechanically challenging task, but a mentally challenging one as well. Being able to understand how all the components work together, putting it all together, and physically making it are criteria each member of the team needs to know to complete such a task. Our mission with this project succeeded, as each member of the team has a much deeper understanding of the Wankel rotary engine, and now can display and teach others how the engine itself functions; knowledge which could be passed on to future teams attempting this MQP.

Reflections

After the manufacturing and construction of a Wankel Rotary engine, our team has learned much. We have learned about the rotary engine itself, the process of how it operates, and the parts which go into one. We have also practiced and developed our skills in manufacturing parts and those processes.

Our ability to overcome the obstacles which appeared in our way allowed us to finish the assembly before the deadline. Choosing different material to machine with as our first choices were too expensive, transferring from SolidWorks to Esprit, and other considerations were small hurdles we had to clear as a group before we could be considered finished. Although our design took longer than it could have, we were still able to manufacture the parts required to construct a rotary engine by the end of C term 2023.

Being able to work on such a project has given not only insight on the automotive industry and their standards and practices, but also the world of advanced manufacturing. Before this point, the team had only worked on smaller scale projects assigned by WPI. Now we have both the experience and knowledge to further our careers and teach others.

Works Cited

Beat Racing. (n.d.). Engine seals. Rotary Tech Tips: Engine Seals. Retrieved January 18, 2023, from
https://www.racingbeat.com/mazda/performance/rotary-tech-tips/engine-seals.html (https://www.racingbeat.com/mazda/performance/rotary-tech-tips/engine-seals.html)

Boughou, Smail & Mohiuddin, A.. (2020). Combustion Chamber Design Effect on The Rotary Engine Performance - A Review. International Journal of Automotive Engineering. 11. 200-212. 10.20485/jsaeijae.11.4_200, https://www.researchgate.net/publication/347189421_Combustion_Chamber_Design_Effect_on_The_Rotary_Engine_Performance_-_A_Review (https://www.researchgate.net/publication/347189421_Combustion_Chamber_Design_Effect_on_The_Rotary_Engine_Performance_-_A_Review)

Hannafin, P. (2018). Rotary Seal Design Guide (Ser. EPS 5350/USA). Parker Hannifin Corporation, Engineered Materials Group, https://www.parker.com/content/dam/Parker-com/Literature/Engineered-Polymer-Systems/5350.pdf (https://www.parker.com/content/dam/Parker-com/Literature/Engineered-Polymer-Systems/5350.pdf)

Hege, J. B. (2015). The Wankel Rotary Engine: A History. McFarland.

Jancer, M. (2018). Why Car Lovers Are So Mad for Mazda’s Rotary Engine Revival. Popular Mechanics. Retrieved Mach 23, 2023, from https://www.popularmechanics.com/cars/car-technology/a7103/mazda-wankel-rotary-engine/ (https://www.popularmechanics.com/cars/car-technology/a7103/mazda-wankel-rotary-engine/)

Kulina, M R. Experimental evaluation of rotary engine timing gear loads. United States.

Kulina, M. R. (1986, January 1). Experimental evaluation of Rotary Engine Timing Gear loads. Experimental evaluation of rotary engine timing gear loads
(Conference) | OSTI.GOV. Retrieved March 23, 2023, from
https://www.osti.gov/biblio/5501534

Mazda. (n.d.). 50 years of Rotary Revolution: We are Mazda. 50 YEARS OF
ROTARY REVOLUTION | We are Mazda. Retrieved January 18, 2023,
from https://www.mazda.com/en/innovation/mazdastories/mazda/rotary_revolution/ (https://www.mazda.com/en/innovation/mazda-stories/mazda/rotary_revolution/)

Mazda. (n.d.). How Mazda Won 24 Hours of Le Mans. We are Mazda. Retrieved March 23, 2023, from https://mazdastories.com/en_us/innovate/how-mazda-won-24-hours-of-le-mans/

Moskowitz, D., Uy, J. C. (1976, September 21). Apex seal composition for rotary engines. (https://patents.google.com/patent/US3981062A/en)

(n.d.). Locating and Clamping Principles. Carr Lane Mfg. Co. Retrieved March 23, 2023, from https://www.carrlane.com/engineering-resources/fixture-design-principles/locating-clamping-principles (https://www.carrlane.com/engineering-resources/fixture-design-principles/locating-clamping-principles)

Mazda Housing design choices PDF (https://www.rx7.net.nz/jhb-tech-complete.pdf)

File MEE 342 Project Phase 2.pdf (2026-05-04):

https://github.com/pnadig1-asu/Redline-Rotaryhttps://youtu.be/lnX_TSrsm9A

Group 3 Phase 2 – Detailed CAD Design & Engineering Analysis

Overview of Design

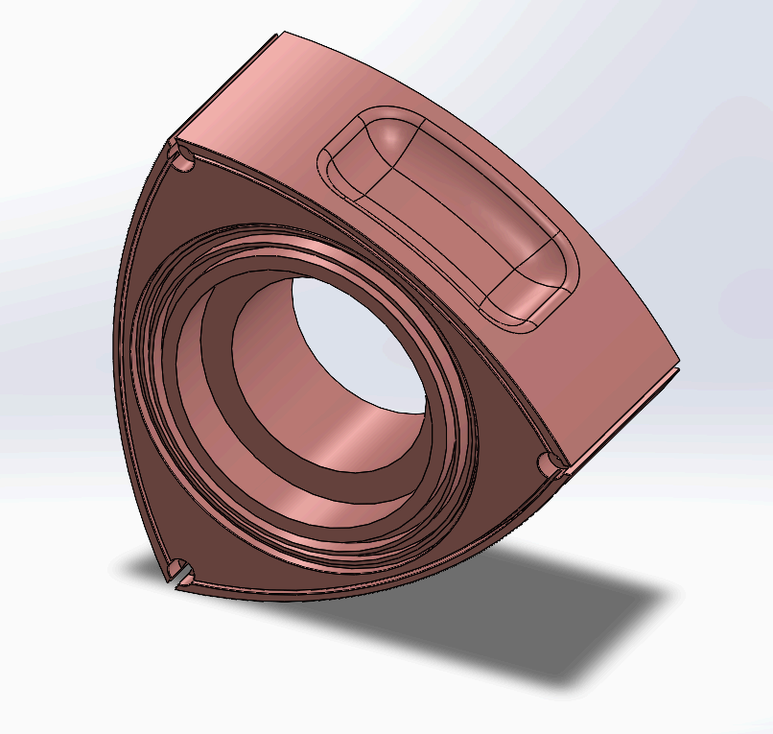
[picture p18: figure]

Rotor
Material: Cast Iron
Function: The rotor spins inside an epitrochoidal housing around the internal stationary gear. As the rotor spins, intake, compression, combustion, and exhaust occur as the chambers change in volume.

Side Seals
Material: Cast Iron (outside seals) & Silicon (inside seals)
Function: The side seals seal blowby compressed gasses and lubricating oil from exposure to each other while also keeping a low-friction contact between the rotor and the side the iron.

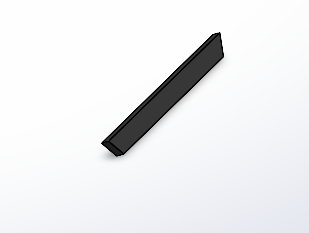
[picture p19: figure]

Apex Seals
Material: Graphite/Steel Ceramic-Metallic Blend Function: Apex seals seal compressed and combusting gasses from each other against the rotor housing while keeping a low-friction contact between them.

Apex Seal Springs
Material: Steel
Function: At high engine speeds, centripetal force pushes the apex seals outwards into the housing, creating the seal. At low engine speeds, the apex seals need help from the side seals pushing them out of the rotor to create sealing. This is necessary because the corners of the triangular geometry of the rotor do not perfectly line up to the shape of the housing, so sealing requires that the apex seal moves in and out of the rotor to compensate for the distance disparity.

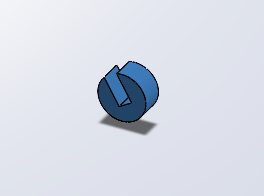
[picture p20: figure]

Apex Seal Washer
Material: Steel
Function: This component is also called the corner seal. It holds the apex and outer side seals at ideal angles for sealing.

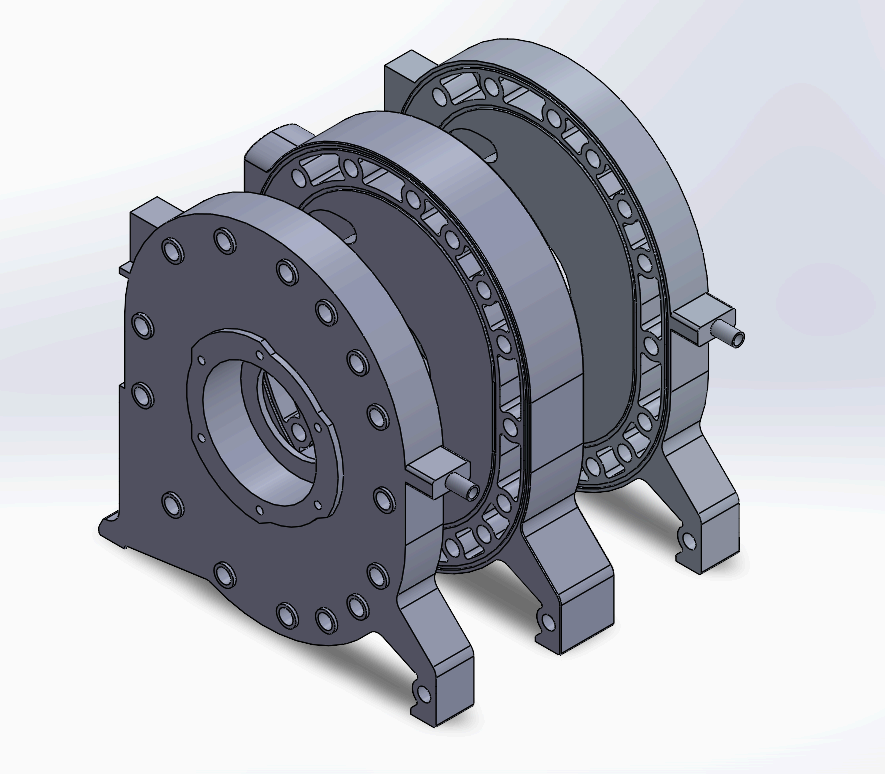
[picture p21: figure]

Irons (front, middle, and rear irons)
Material: Cast Iron and Chromium
Function: The irons seal the sides of the combustion chambers and rotors. While the entire component is made of cast iron, the surface against the rotor is made of smooth hard chromium to reduce friction and increase sealing efficiency. Channels for coolant, engine air intake, hardware adaptations, and crankshaft bearings are incorporated into these designs.

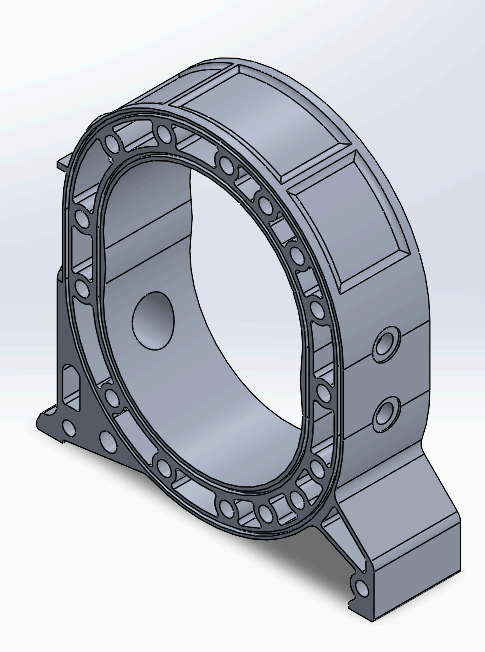
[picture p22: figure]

Rotor Housings
Material: Cast Aluminum, Chromium, and Inconel Function: The two housings encase the rotors along with the irons. Their aluminum construction allows for thermal expansion, and the chromium surface provides excellent sealing and friction properties against the apex seals. Spark plug and exhaust bores are incorporated into the design.

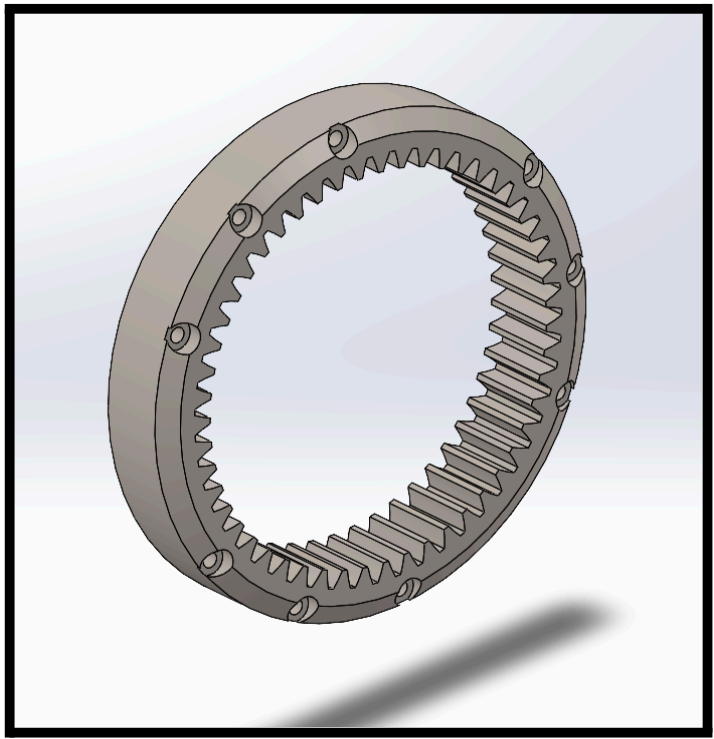
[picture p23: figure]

Rotor Internal Spur Gear
Material: Cast Iron
Function: The internal spur gear is fixed to the rotor. It meshes with the stationary gear and prevents the rotor from freely spinning. This synchronizes the rotor’s movement with the eccentric shaft which allows proper combustion timing to occur.

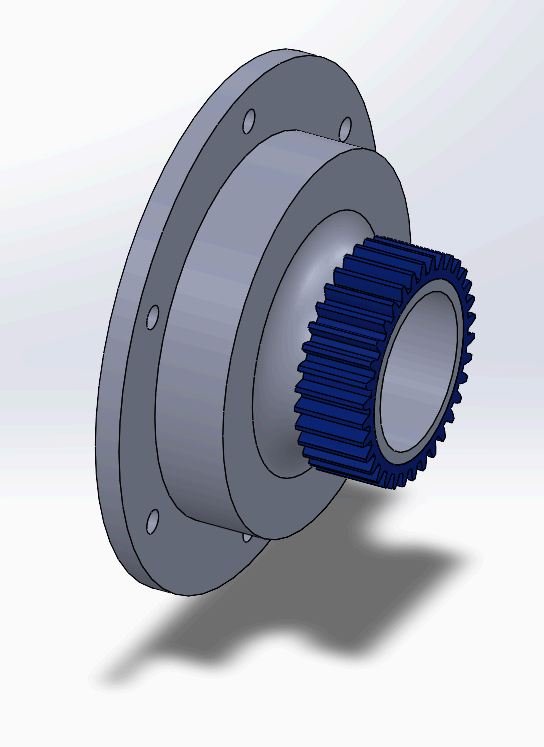
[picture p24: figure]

Stationary Gear
Material: Cast Iron
Function: This stationary gear is bolted to the iron and guides the motion of the rotor using a 3:2 gear ratio in a spur gear system.


Eccentric Shaft
Material: 4340 Billet Steel
Function: The eccentric shaft is the crankshaft of the wankel engine, converting the spinning motion of the rotors into harnessable torque. The E-shaft has internal oil passages to lubricate the bearings between itself and the rotor and engine irons.

Tolerances & Drawings


In a wankel engine, the crankshaft and rotor have a journal bearing system to keep it lubricated at potential speeds of 10,000rpm. In our model, the eccentric shaft lobe diameter is 2.95in. Since our model is simplified, the bearing inner diameter on the rotor also has a diameter of 2.95in. Obviously, in real life, these two diameters cannot be the same; there has to be a gap between the two diameters for oil to get in there and lubricate. For a targeted oil clearance of 0.001in, appropriate tolerances for the E-shaft would be 2.9495-2.95in and 2.9505-2.9510in for the rotor bearing.


For the crankshaft bearings against the irons, the crankshaft journal diameter is at 1.6895-1.6900in and 1.6905-1.6910in for the bore in the engine iron.


Analysis & Major Design Changes

Main Rotor Analysis


Above is a FEA analysis of our cast iron rotor under centrifugal load. This is the rotor under a simulated maximum loading of 10,000 RPM creating a maximum loading of 173.11 MPa in the rotor.
At first, cast iron was used as the material, but realistically the rotor had a higher Poisson’s ratio and Young’s modulus than the data in ANSYS. Before editing these properties, part of the rotor face would be crushed under the pressure from combustion. After editing the properties, all of the solution numbers looked much more realistic.

Eccentric Shaft Analysis


Equivalent Stress of Eccentric Shaft


Fatigue safety factor for Infinite Life


Stress Safety Factor

Just like the rotor analysis, changing material properties was our first major edit. After switching from structural steel to AISI 4340 Billet Steel, which is the material Mazda uses in 13B eccentric shafts, the stress factor of safety jumped from barely over 1 to a more appropriate 1.7. However, that is still too low, and there were heavy stress concentrations between the eccentric lobes and the rest of the shaft. After increasing the fillet radius on the geometry, the factor of safety increased to an appropriate 4.17. Upon running the fatigue analysis, however, we noticed that the fatigue safety factor was very low, at around 0.2. This is due to the insufficient fillet and output shaft radii. Using this data, we were able to make some design changes. The keyway on the output shaft was also removed as this keyway will be supported by its respective mate in a real world scenario, so it was removed to simplify the analysis. Increasing the fillet radii to 1.5mm and the output shaft radii to 34mm, resulted in a much higher fatigue factor of safety of 1.1143. This may seem lower than is desirable for a part like this, but remember that this is the fatigue factor of safety, and the stress factor of safety. Routine inspections and maintenance will reveal true wear of this part so it can be replaced before catastrophic failure, and indicate that fatigue is the governing failure mode for this part.

Internal Gear Analysis


Above is another FEA analysis of the internal gear that is inside the rotor head. This is under near max conditions again with the engine at 10,000 rpms so we put a force of 1,000 newtons on one tooth face. The gear as a whole experienced a maximum of 42.03 MPas in equivalent stress. The gear also has a running safety factor of about 6 which is very respectable.


Above is the same gear but under centrifugal forces where the gear is spinning at about 10,000 rpm. The gear is experiencing a maximum of 45.958 MPa of equivalent stress which is an acceptable loading as our factor of safety ramin at around 6.


Above is a fatigue analysis of the gear which results in a factor of safety of 2.0509 which is very good for a part like this where one tooth is experiencing a force of over 1000 Newton which is similar to what a single tooth would experience when the rotor is spinning at 10,000 rpm and meshing with the other spur gear.

Bearing Analysis
This rotary engine uses journal bearings, similar to most other internal combustion engines. These work by providing two smooth surfaces where oil can be applied to reduce friction, drag and wear. It is very important that these two surfaces are always separated by a thin film of oil. This film of oil can be described through the Sommerfeld number. This is a dimensionless number that explains how thick the lubricant film between two moving parts is. Low Sommerfeld numbers indicate lubricant film breakdown and can lead to higher wear, temperatures, and lower part life. High Sommerfeld numbers indicate very thick lubricant film with possible efficiency loss. A plot of the Sommerfeld number vs. engine RPM can be seen here:


Notice how the rate of increase of the Sommerfeld number drops off near max RPM. This is due to the decreased viscosity of the oil at higher temperatures. At standard operating speeds (2-3k RPM) the Sommerfeld number is around 2.5, which is perfect for these types of bearings. At higher RPM, the sommerfeld number is closer to 7, which is rather high, but it ensures the longevity of the bearings and the small efficiency loss is simply a tradeoff of this. Overall, the bearings will hold up to long term use inside this engine.

Model Assembly for 3D printing

The design uses bolt patterns and aligned holes to keep the rotor housing together. The journal bearings keep the e-shaft aligned with the centerpoint while allowing rotation through the combustion process. The design of the main components allow for 3D printing because of the orientation of the components on the build plate. This model should be able to be scaled down a couple times to be 3D printed on a standard sized printer. Luckily, with this model there are not too many overhangs, and the amount of support trees needed are not too much making the 3D printing process relatively simple. Critical components used in the 3D printed prototype assembly include the rotor, eccentric shaft, rotor housings, and engine irons. Including smaller seals are not necessary for this prototype due to added restriction, but this is acceptable because a plastic model was never meant to achieve vacuum, compression, or combustion that requires precise sealing.

Risks and Weaknesses

3D printing is not an ideal form of prototyping for an engine model because of the imprecision. Since plastic expands anywhere from 0.1% - 1%, precise dimensions and tolerances are very difficult to achieve with 3D printed parts. The precision needed for proper combustion sealing is in the thousandths of an inch for a full sized engine, so even with accurate expansion calculations and high quality printing, a 3D printed engine cannot generate necessary vacuum and compression. However, for our prototype, we never aimed to achieve combustion; instead we are opting for the correct mechanics. 3D printing absolutely has the precision for our engine to cycle accurately as long as we are careful with printing tolerances. By decreasing outer diameters in bearing surfaces, eliminating seal components, and smoothing out rough printed surfaces through sanding, a printed model can achieve correct dynamics. To improve the prototype, decreasing gear teeth numbers and increasing teeth depth in appropriate ratios will smooth out the rotation of the rotor in the housing. Another weakness of the 3D printed model is heat tolerance. Real engines operate at over 200 degrees; at that temperature the 3D printed plastic is heavily deforming. Because of this, our engine cannot be spun at comparable speeds to machined and cast metal prototypes.

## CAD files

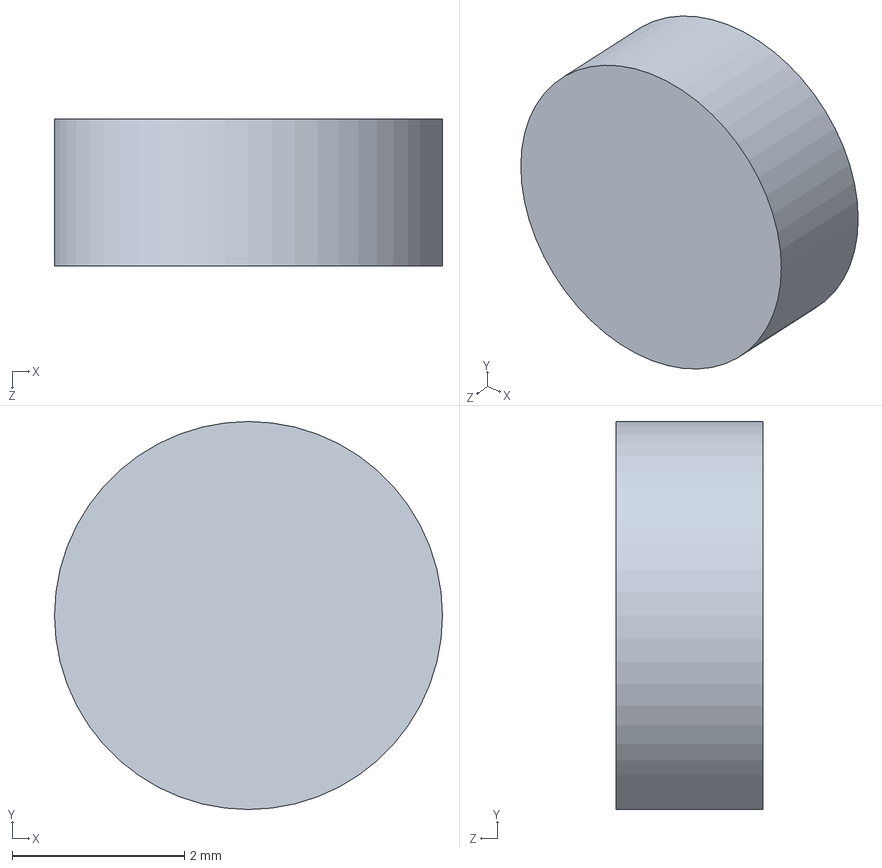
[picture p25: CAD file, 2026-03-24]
cad/rewankelrotaryengine-2/electrodes connector.SLDPRT
4.50 x 4.50 x 1.70 mm

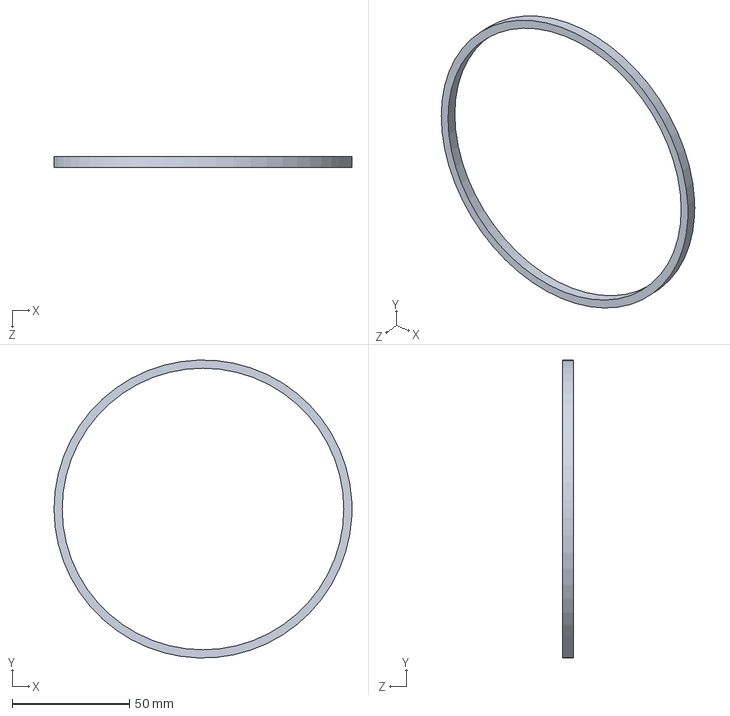
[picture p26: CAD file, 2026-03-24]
cad/rewankelrotaryengine/sideseal2.SLDPRT
127.0 x 126.9 x 4.50 mm

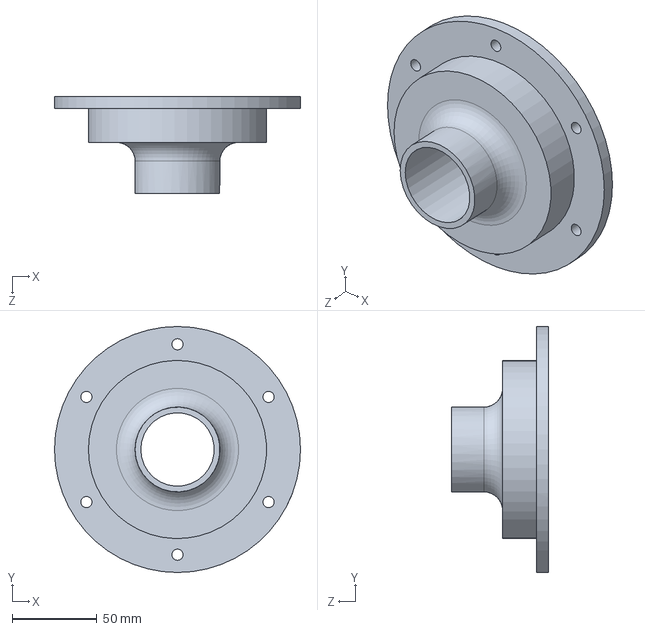
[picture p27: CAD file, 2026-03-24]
cad/rewankelrotaryengine-2/frontrear gear shaft.SLDPRT
145.0 x 145.0 x 57.0 mm

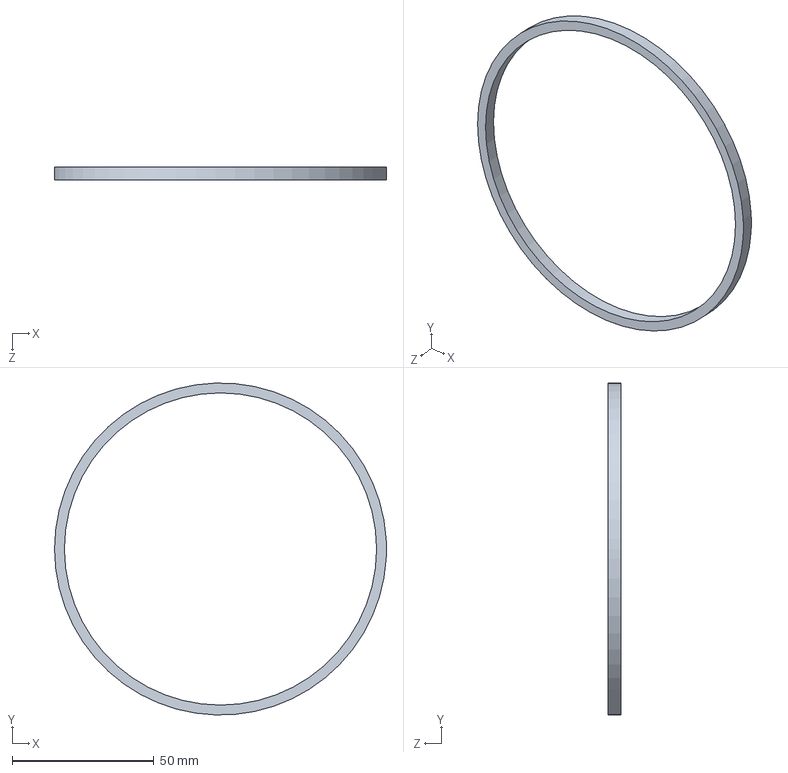
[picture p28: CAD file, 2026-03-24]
cad/rewankelrotaryengine/sideseal.SLDPRT
117.0 x 116.9 x 4.50 mm

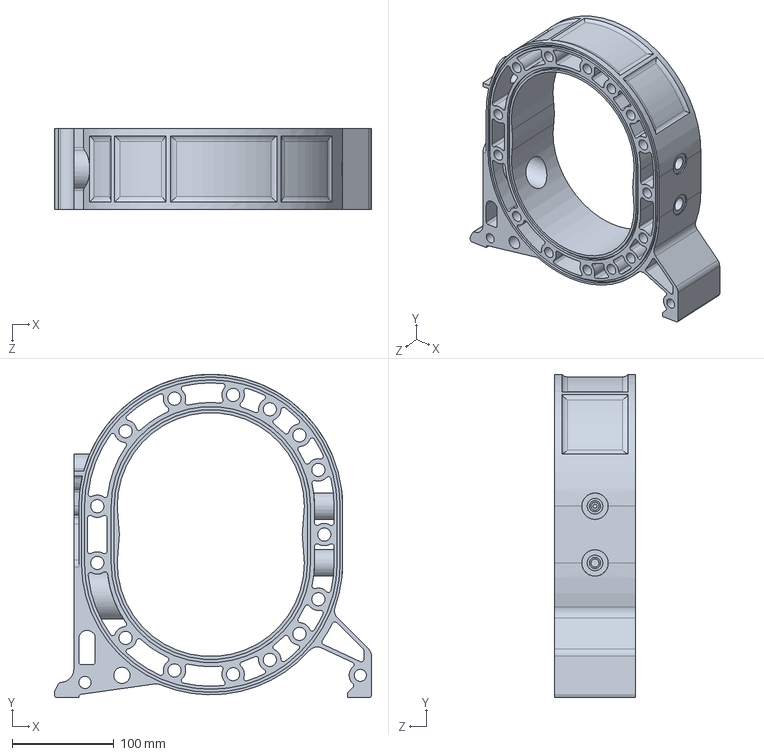
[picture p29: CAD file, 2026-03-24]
cad/rewankelrotaryengine-2/rotor housing.SLDPRT
311.7 x 317.9 x 80.0 mm

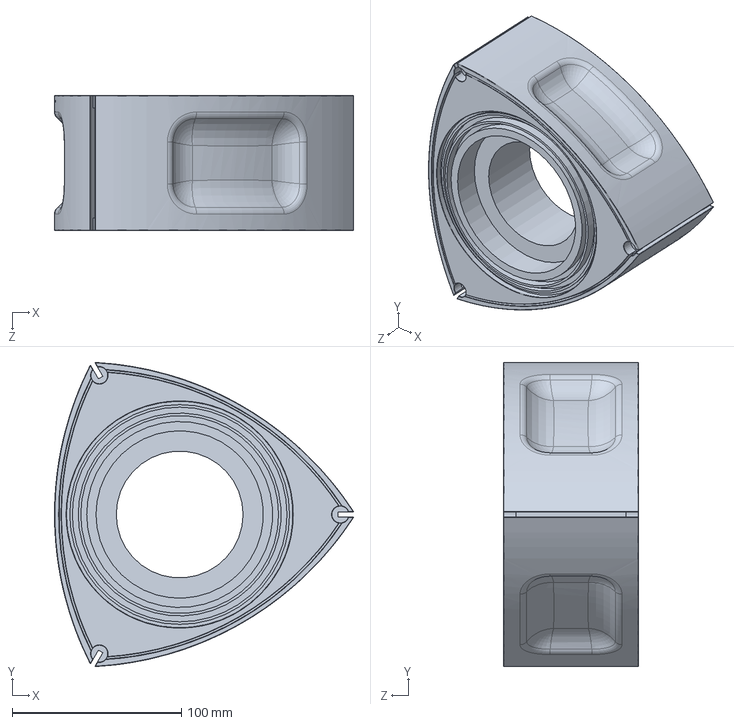
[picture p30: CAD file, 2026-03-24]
cad/rewankelrotaryengine/Rotor head.SLDPRT
176.9 x 179.9 x 80.0 mm

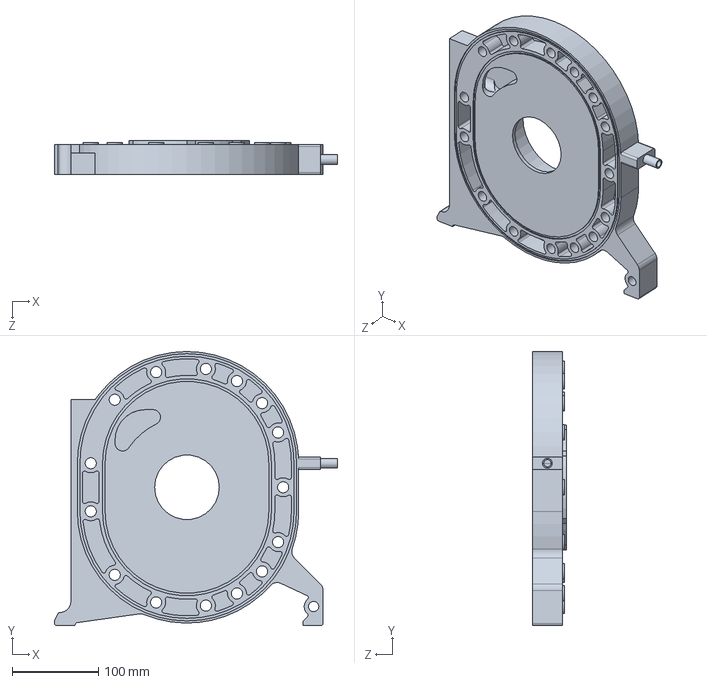
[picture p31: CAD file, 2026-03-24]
cad/rewankelrotaryengine-2/rear plate.SLDPRT
328.4 x 317.9 x 40.0 mm

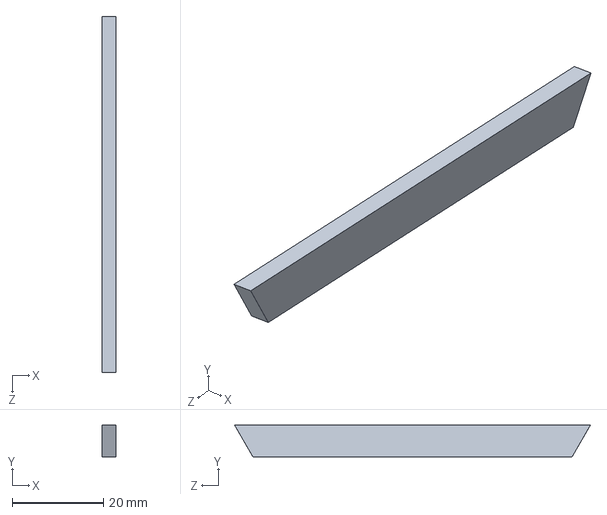
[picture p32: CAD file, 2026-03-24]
cad/rewankelrotaryengine/apex seals.SLDPRT
3.00 x 7.00 x 78.0 mm

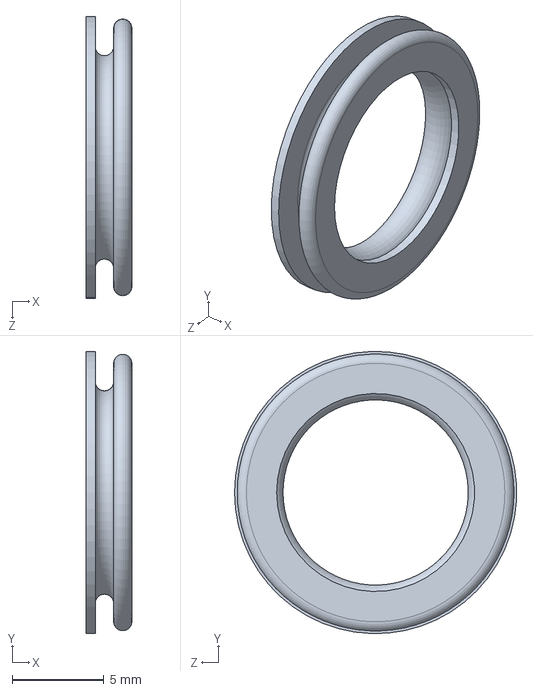
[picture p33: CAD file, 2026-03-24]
cad/rewankelrotaryengine-2/gasket.SLDPRT
2.50 x 15.4 x 15.4 mm

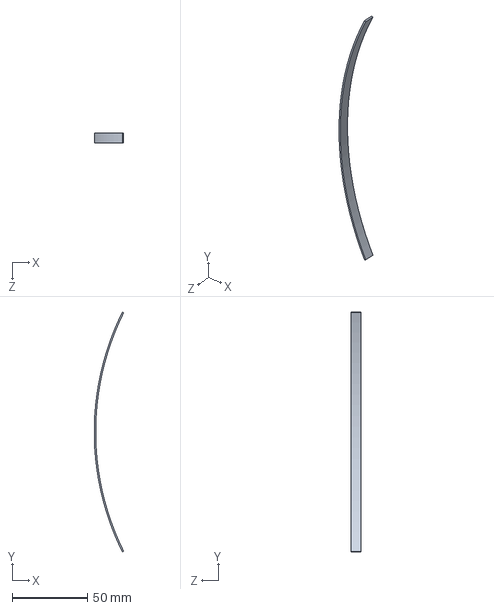
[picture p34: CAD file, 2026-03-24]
cad/rewankelrotaryengine/sideseal3.SLDPRT
19.6 x 159.5 x 6.75 mm

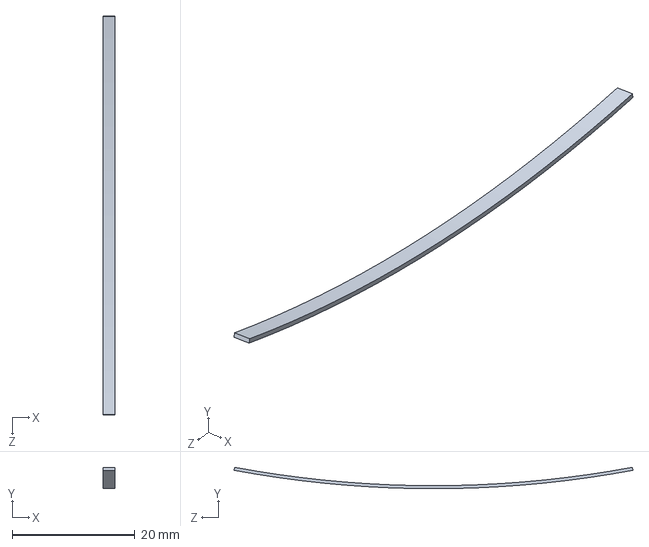
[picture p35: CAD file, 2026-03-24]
cad/rewankelrotaryengine-2/springs for apex seals.SLDPRT
2.00 x 3.49 x 65.0 mm

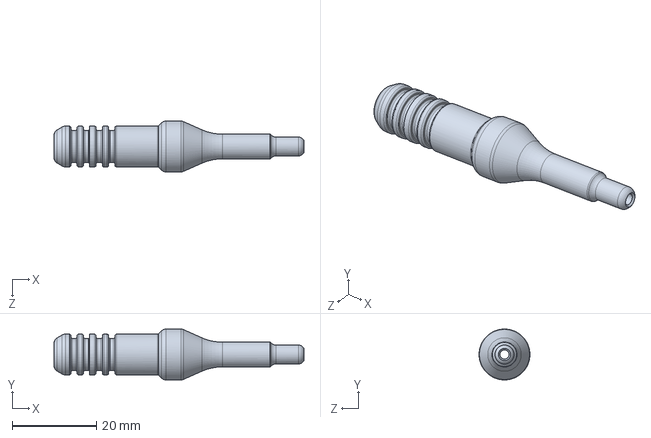
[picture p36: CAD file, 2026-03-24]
cad/rewankelrotaryengine-2/insulator.SLDPRT
59.5 x 12.1 x 12.1 mm

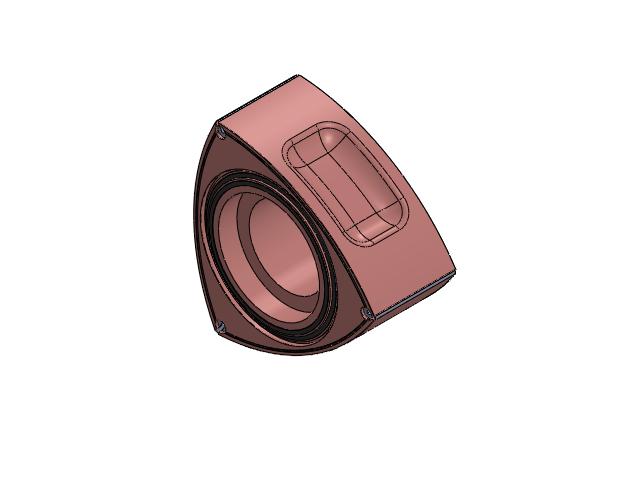
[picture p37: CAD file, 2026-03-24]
cad/rewankelrotaryengine/Rotor Head assembly.SLDASM
Rotor head
gearforrotor
sideseal x 2
sideseal2 x 2
sideseal3 x 6
apex seals x 3
springs for apex seals x 3
apex seal washer x 6
socket head cap screw_iso x 9

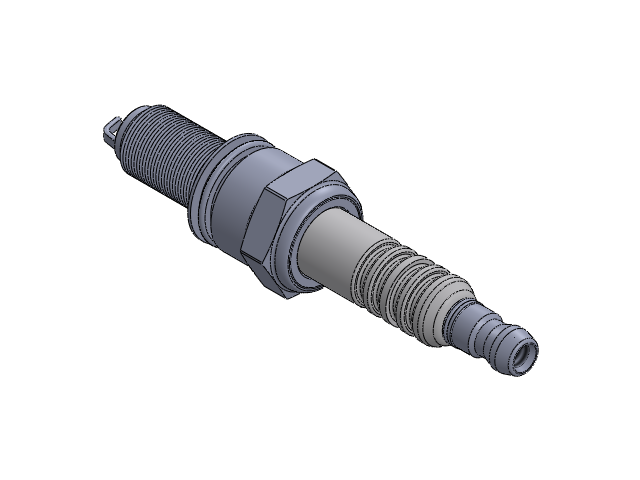
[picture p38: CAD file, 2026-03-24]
cad/rewankelrotaryengine-2/sparkplug1.SLDASM
hexagon
insulator
Center electrode
Terminal nut
electrode
gasket
lock but
electrodes connector

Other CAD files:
cad/rewankelrotaryengine-2/wankel assembly.SLDASM
cad/rewankelrotaryengine-2/Rotor Head assembly.SLDASM
Extra Files/eccentric shaft.SLDDRW
cad/eccentric shaft.SLDDRW
cad/rewankelrotaryengine-2/Center block.SLDPRT
cad/rewankelrotaryengine-2/Center electrode.SLDPRT
cad/rewankelrotaryengine-2/Front plate.SLDPRT
cad/rewankelrotaryengine-2/Inner gasket.SLDPRT
cad/rewankelrotaryengine-2/Terminal nut.SLDPRT
cad/rewankelrotaryengine-2/apex seal washer.SLDPRT
cad/rewankelrotaryengine-2/eccentric shaft.SLDPRT
cad/rewankelrotaryengine-2/electrode.SLDPRT
cad/rewankelrotaryengine-2/hexagon.SLDPRT
cad/rewankelrotaryengine-2/lock but.SLDPRT
cad/rewankelrotaryengine-2/outer gasket.SLDPRT
cad/rewankelrotaryengine/apex seal washer.SLDPRT

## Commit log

2026-03-24 Rotor head assembly
    [Center block.SLDPRT, Center electrode.SLDPRT, Front plate.SLDPRT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]
2026-03-25 Add files via upload
    This file runs calculations on the journal bearing analysis for the journal bearings that support the eccentric shaft of the wankle rotary engine
